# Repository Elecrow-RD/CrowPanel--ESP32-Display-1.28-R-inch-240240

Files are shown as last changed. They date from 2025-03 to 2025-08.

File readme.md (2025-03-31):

### 1, Product picture

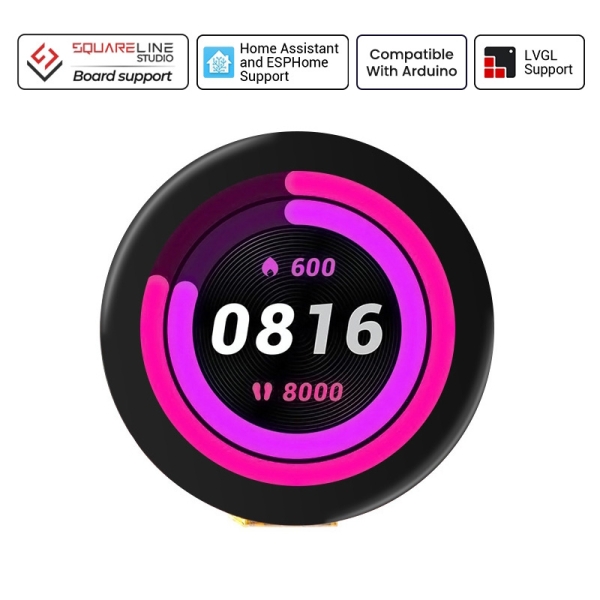
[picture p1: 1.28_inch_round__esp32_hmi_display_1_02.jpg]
1.28_inch_round__esp32_hmi_display_1_02


### 2, Product version number

| | Hardware | Software | Remark |
| ---- | --- | --- | --- |
| 1 | V1.0 | V1.0 | latest |

### 3, product information

#### Display Module Specifications

| Main Chip | ESP32-C3 |
| --- | --- |
| Processor | 32-bit RISC-V single-core processor, up to 160 MHz |
| Memory | 384 KB ROM400 KB SRAM (16 KB for cache)8 KB SRAM in RTC |
| Size | 1.28 inch |
| Resolution | 240*240 |
| Signal Interface | SPI |
| Touch Type | Capacitive Touch |
| Panel Type | TFT LCD, IPS Panel |
| Color Depth | 262K |
| Brightness | 350 cd/m² |
| Viewing Angle | 178° |
| Button | Rest Butto, Boot Button, Custom Button |
| Interface | Type-C Interface, Battery Interface |
| Encoder | With Button Function, Without Pin (Pin Size: 0.8mm*0.8mm) |
| Operation Power  | Module: DC5VMain Chip: 3.3V |
| Active Area | 32.51*32.51mm |
| Dimensions | 42*42*9.8mm |
| Net Weight | 15g |

### 4, Use the driver module

### 5,Quick Start

##### Arduino IDE starts

1.Download the library files used by this product to the 'libraries' folder.

C:\Users\Documents\Arduino\libraries\



2.Open the Arduino IDE

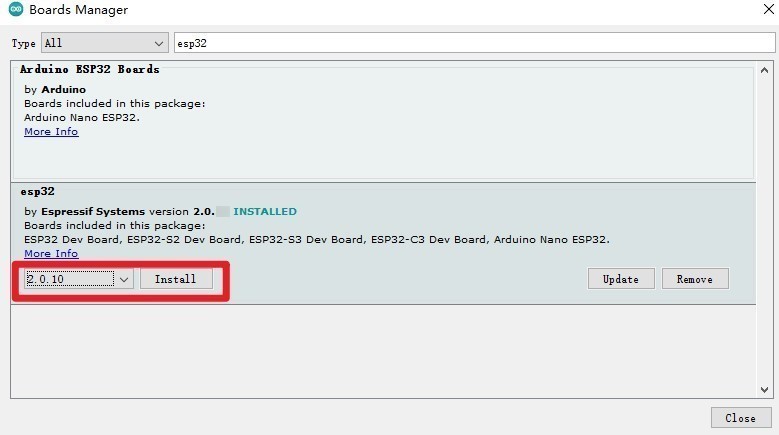
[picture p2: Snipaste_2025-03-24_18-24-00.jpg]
Snipaste_2025-03-24_18-24-00


3.Open the code configuration environment and burn it

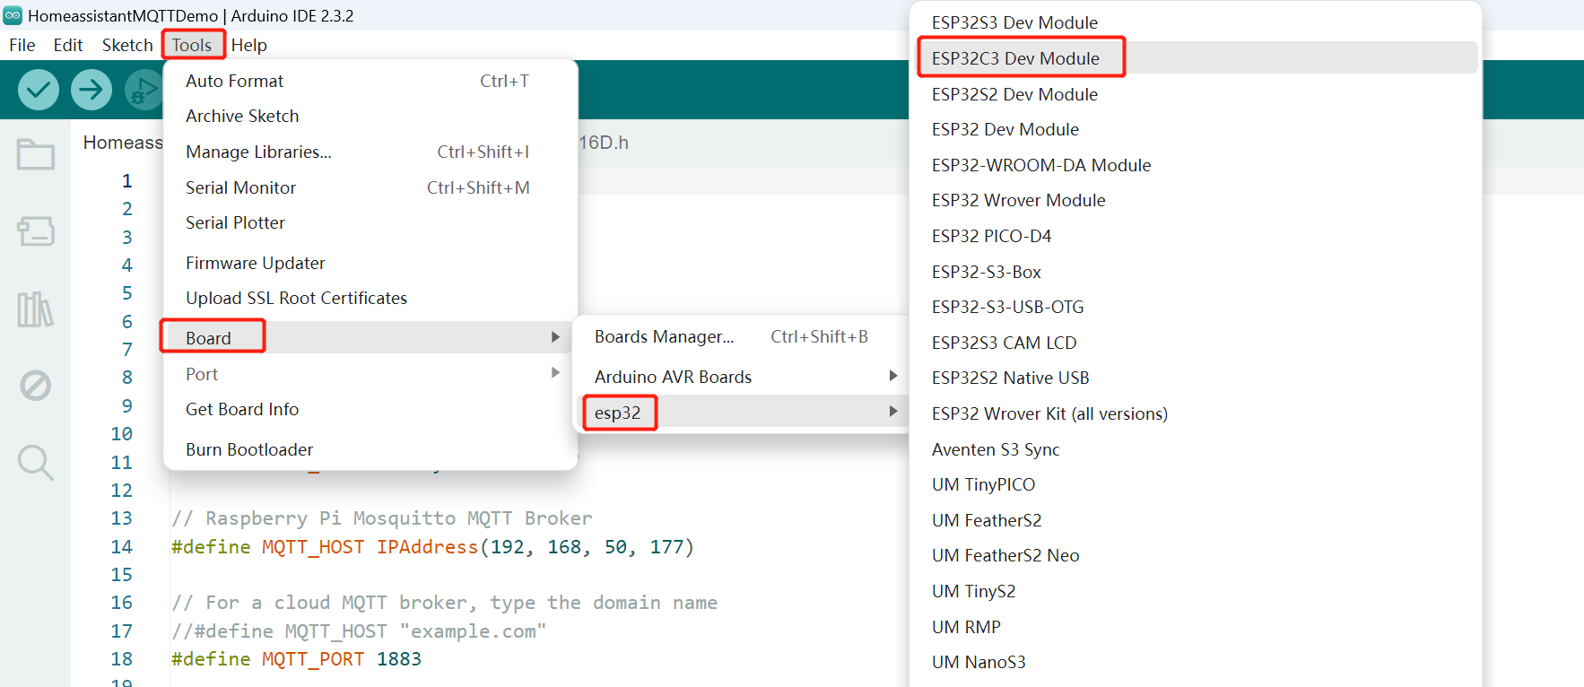
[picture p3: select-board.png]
select-board


##### Micropython starts

1,Right-click on an empty space in the project folder and select "Thonny" to open the project.

thonny

2,In thonny software, select the master and port, then run the program

thonny2

### 6,Folder structure.

|--3D file： Contains 3D model files (.stp) for the hardware. These files can be used for visualization, enclosure design, or integration into CAD software.

|--Datasheet: Includes datasheets for components used in the project, providing detailed specifications, electrical characteristics, and pin configurations.

|--Eagle_SCH&PCB: Contains **Eagle CAD** schematic (`.sch`) and PCB layout (`.brd`) files. These are used for circuit design and PCB manufacturing.

|--example: Provides example code and projects to demonstrate how to use the hardware and libraries. These examples help users get started quickly.

|--factory_firmware: Stores pre-compiled factory firmware that can be directly flashed onto the device. This ensures the device runs the default functionality.

|--factory_sourcecode: Contains the source code for the factory firmware, allowing users to modify and rebuild the firmware as needed.

### 7,Pin definition

#define I2C_SDA 4

#define I2C_SCL 5

#define TP_INT 0

#define TP_RST -1

//encoder

#define ENCODER_A_PIN 19

#define ENCODER_B_PIN 18

#define SWITCH_PIN    8

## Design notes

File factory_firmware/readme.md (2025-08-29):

# How to install the factory demo firmware with flash download tool?

#### 1.Preparation:

- USB C cable
- Laptop/PC
- Crowpanel Advance HMI ESP32 AI Display
- Flash download tool

Check whether the materials on the PCBA board are defective. Such as less material, false welding, tin and other bad phenomena.

#### 2.Flash the firmware 

##### Step1 Connect the ESP32 display to the laptop/PC with USB-C cable. The power indicator will light up.

flash-0

##### Step2 Open the flash download tool. 

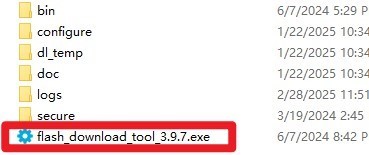
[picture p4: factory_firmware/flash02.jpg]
flash02


For the  Crowpanel Advance HMI ESP32 AI Display, the chip select ESP32-C3:

![Uploading flash03.jpg…]()

##### Step3

①Choose the firmware files;

flash0

②Enter the address: 

boot_app0.bin------0xe000

xxxx.ino.bin--------0x10000

xxxx.ino.bootloader.bin------0x0

xxxx.ino.partitions.bin-------0x8000

③Check the firmware files;

④Select the correct port number;

⑤Click “Start” to download

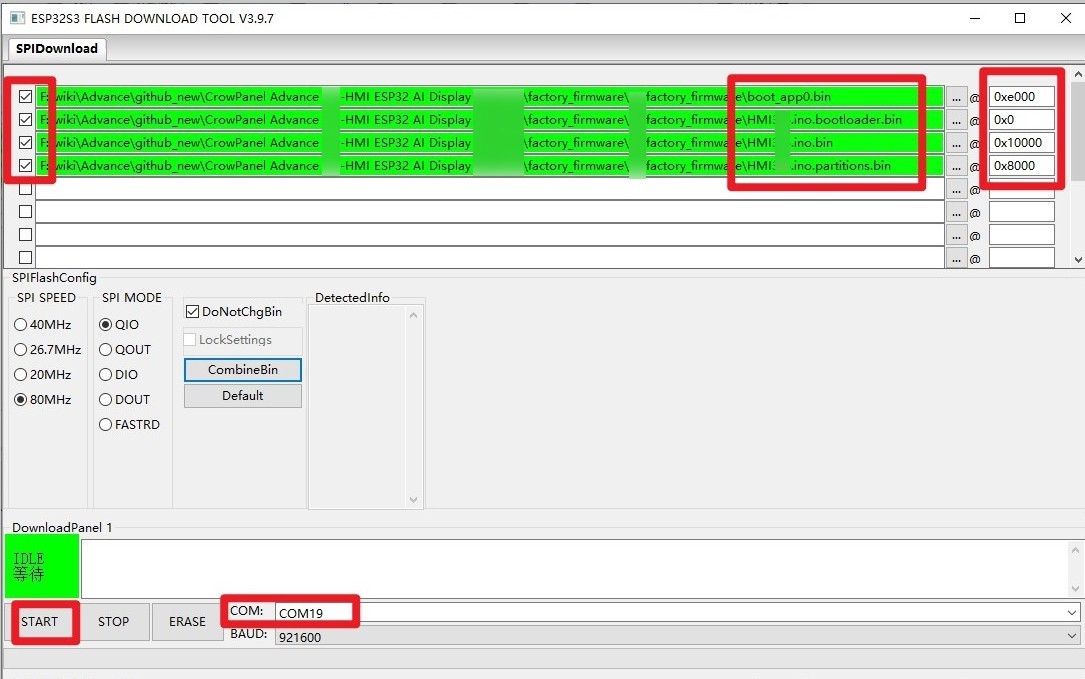
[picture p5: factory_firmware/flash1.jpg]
flash1


##### Step5 After the download is complete, blue FINISH will be displayed, and the progress bar at the bottom shows that it has come to an end.

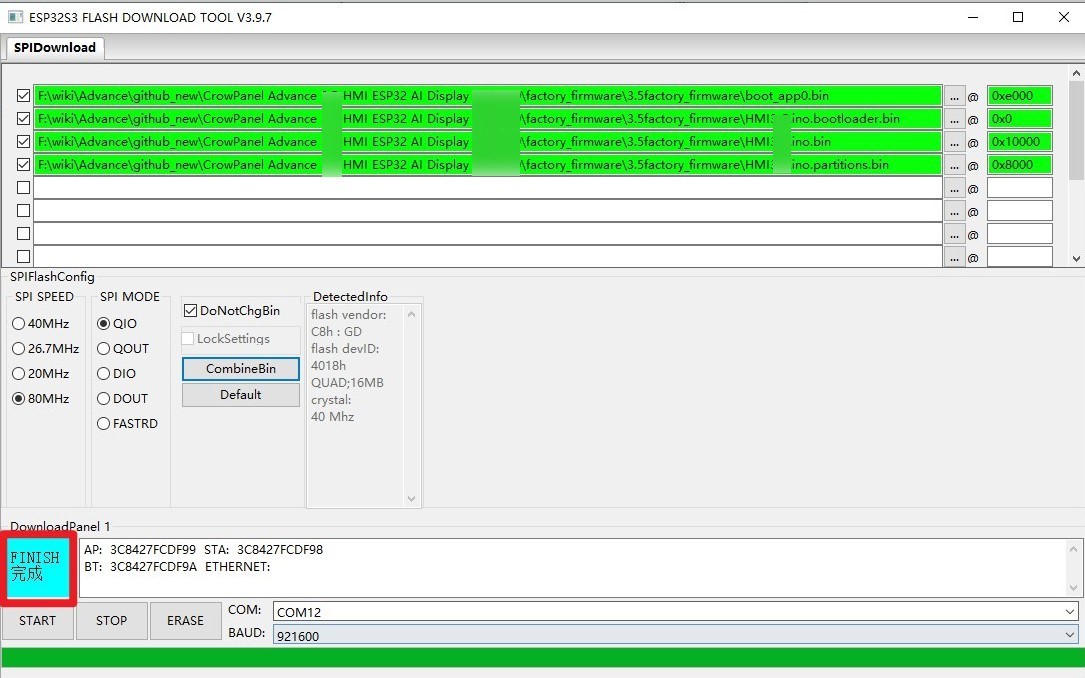
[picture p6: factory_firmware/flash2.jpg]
flash2


##### Step6 Press the reset button to show the demo.

flash8

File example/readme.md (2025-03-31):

**Arduino**: This folder contains sample programs for the Arduino platform, which is known for its ease of use and versatility in creating interactive electronic projects.

#### NOTE!!!:When running this program , you need to download the officially provided libraries and place them in the libraries of arduino. esp32 version needs to be 2.0.10 the version of the libraries is the same as the officially provided version.

Link to the corresponding course wiki:https://www.elecrow.com/wiki/ESP32_1.28-inch_Round_Display_Tutorial.html#tutorial-on-arduino-ide

### homeassistant：

https://www.elecrow.com/wiki/ESP32_1.28-inch_Round_Display_Tutorial.html

### micropython ：

https://www.elecrow.com/wiki/ESP32_1.28-inch_Round_Display_Tutorial.html#tutorial-on-thonny-ide

### Chronos APP:

https://www.elecrow.com/wiki/ESP32_1.28-inch_Round_Display_Chronos_Tutorial.html

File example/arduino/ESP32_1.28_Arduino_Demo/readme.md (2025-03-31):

### Libraries Introduction

1. **async-mqtt-client-develop**
   - An asynchronous MQTT client library for communication with MQTT servers.

2. **ESPAyncUDP**
   - An asynchronous UDP library designed for ESP8266 and ESP32 microcontrollers, compatible with Arduino environment.

3. **LovyanGFX**
   - A graphics library that supports various display devices, commonly used to drive TFT displays and other graphical interfaces.

4. **Lvgi**
   - Likely a specific-purpose graphics or interface library.

5. **lv_conf.h**
   - Configuration file for LVGL (Light and Versatile Graphics Library), used to set and customize the behavior and features of LVGL.

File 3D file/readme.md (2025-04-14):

#### Download link address：
https://www.elecrow.com/download/product/DIS12824D/CrowPanel_ESP32_Display1.28_3D_file.zip

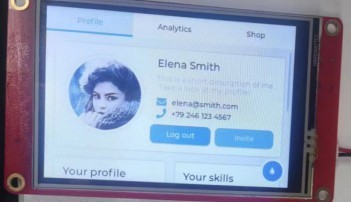
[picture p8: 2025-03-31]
factory_firmware/flash8.jpg

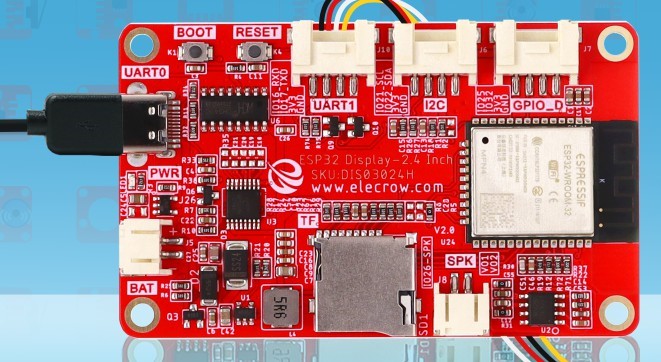
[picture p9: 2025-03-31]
factory_firmware/flash01.jpg

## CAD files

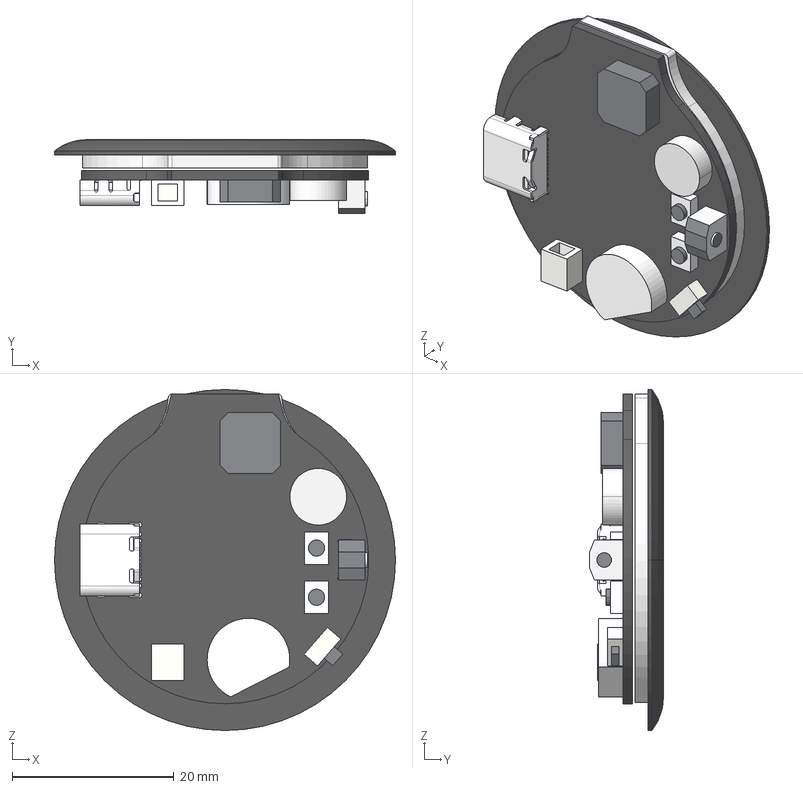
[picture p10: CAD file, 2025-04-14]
3D file/CrowPanel ESP32 Display1.28_asm(2).stp
42.1 x 9.10 x 42.1 mm
LCD-MIANBAN
LCD-JIAOTIE
PCB
TYPE_C_20241129

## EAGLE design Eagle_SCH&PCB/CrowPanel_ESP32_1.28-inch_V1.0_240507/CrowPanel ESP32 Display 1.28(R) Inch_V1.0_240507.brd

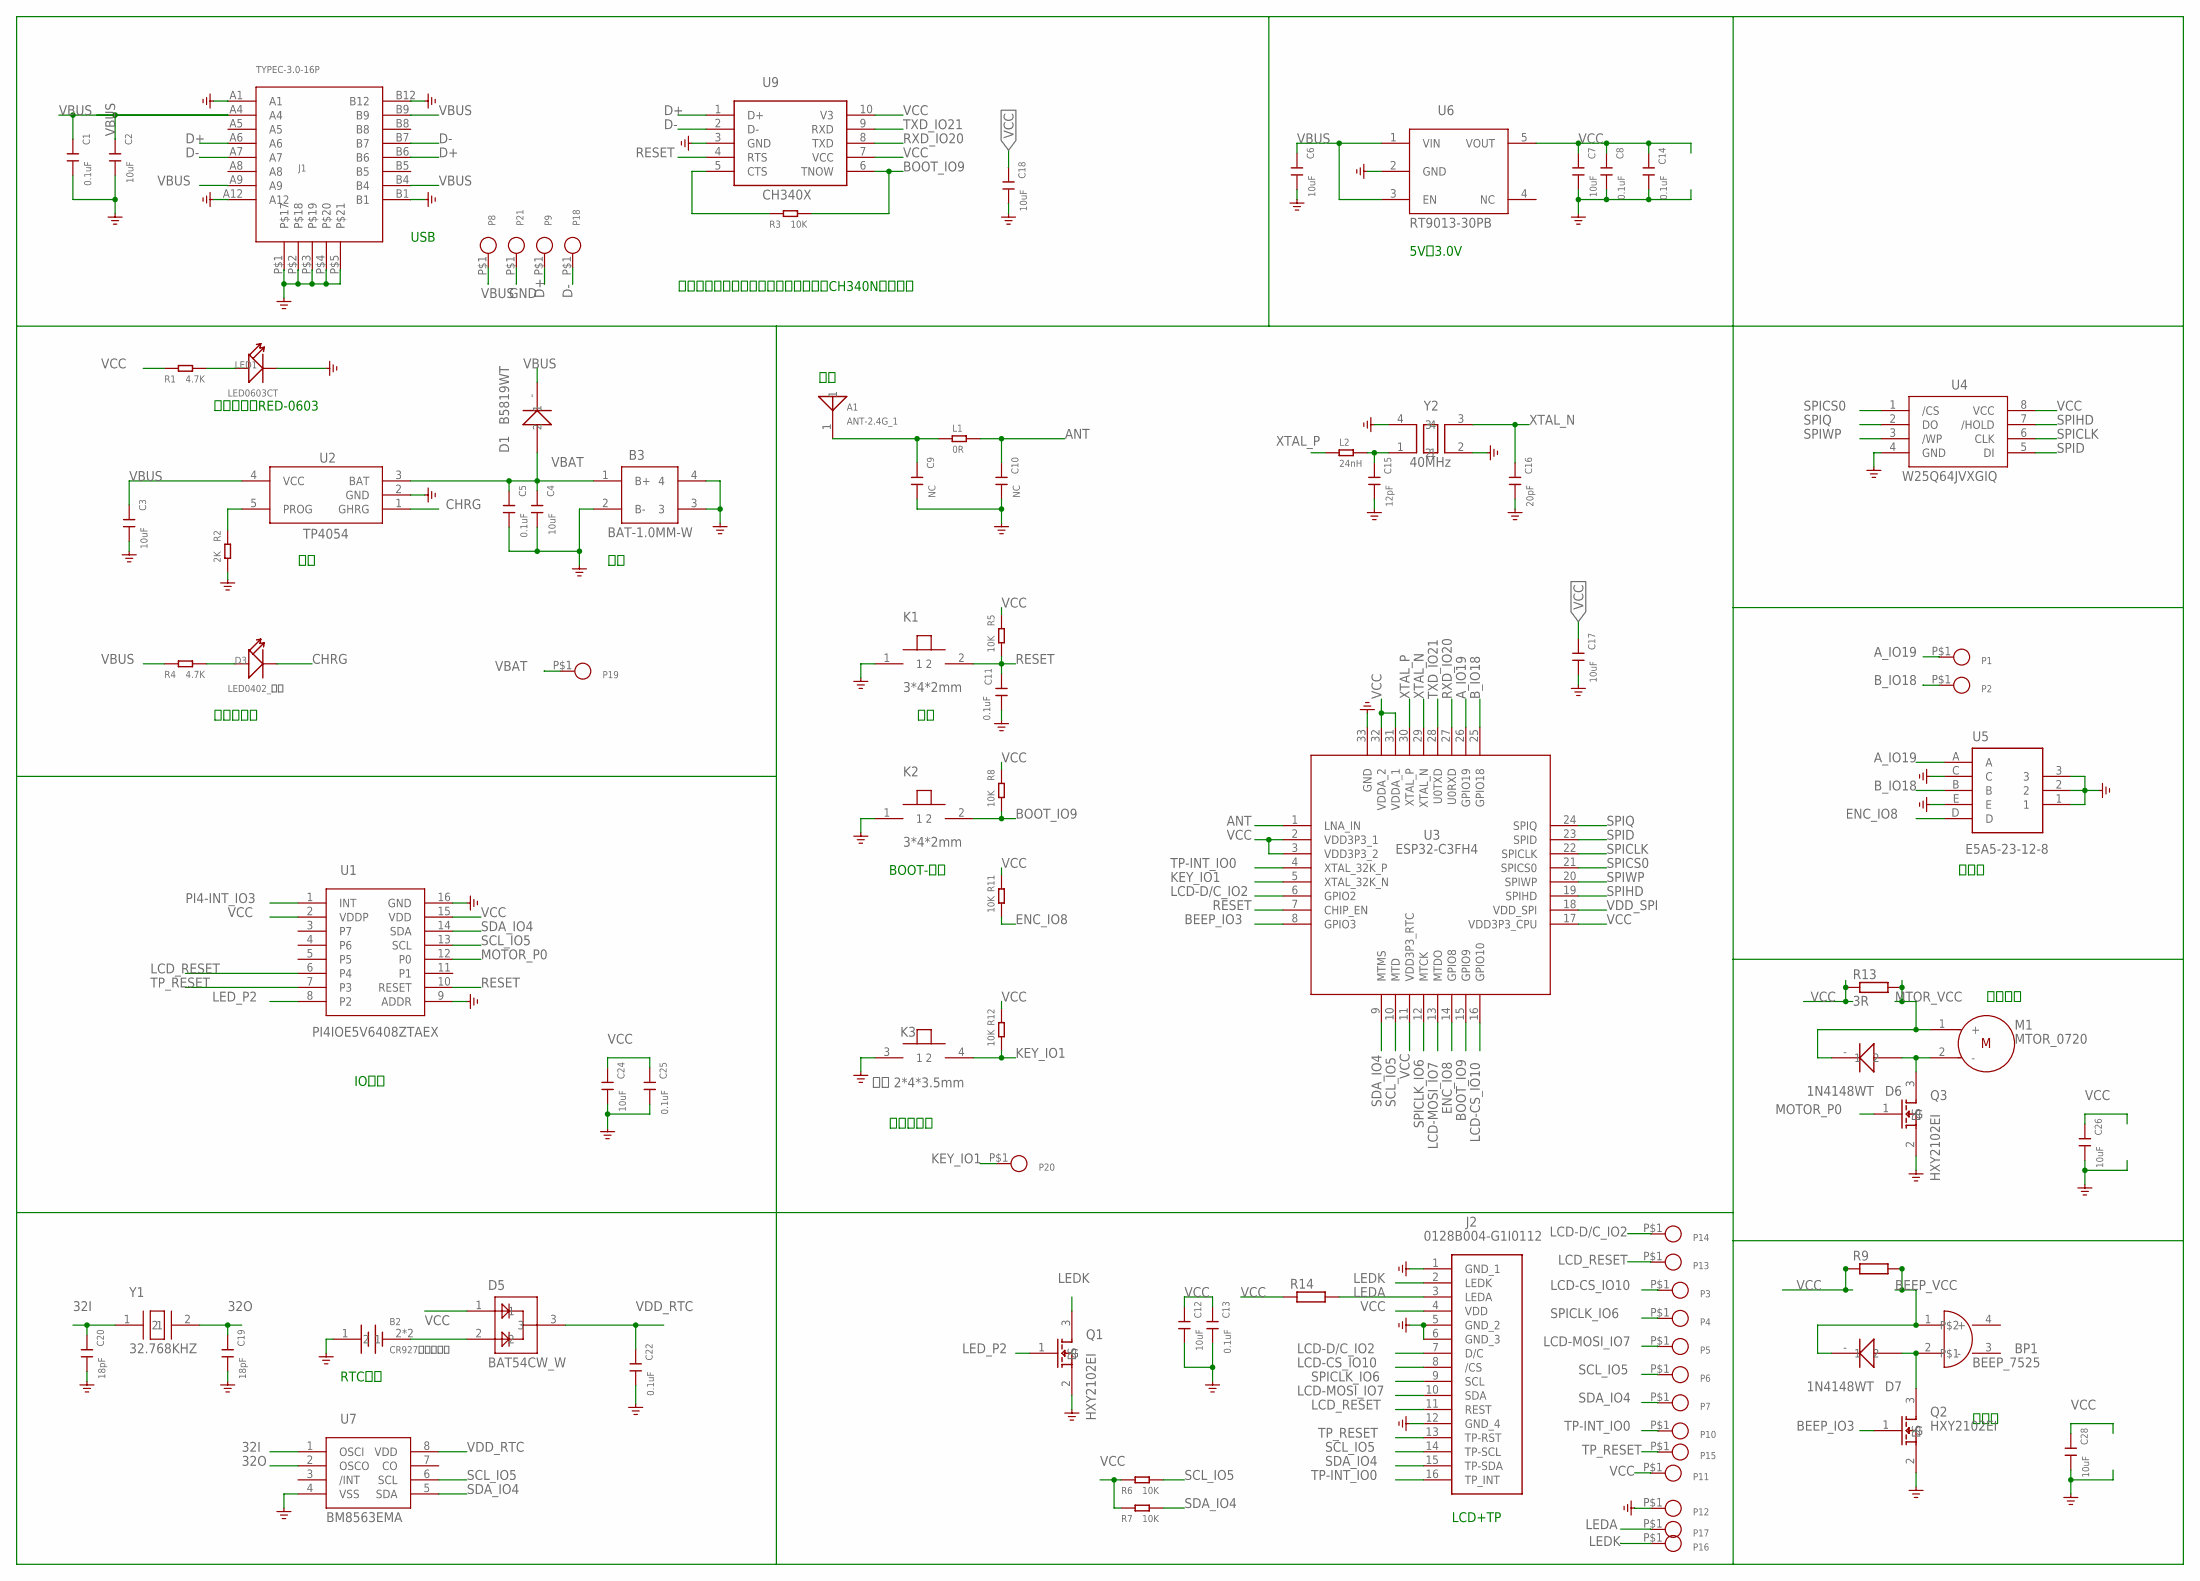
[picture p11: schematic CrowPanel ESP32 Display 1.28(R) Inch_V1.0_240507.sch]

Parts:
A1: ANT-2.4G_1
B2: CR927纽扣电池座; POWER-BAT
B3: BAT-1.0MM-W; SH1.0MM-W
BP1: BEEP_7525
C1, C5, C8, C11, C13, C14, C22, C25: 0.1uF; 0201_W
C2, C3, C4, C6, C7, C12, C17, C18, C24, C26, C28: 10uF; 0402
C9, C10: NC; 0201_W
C15: 12pF; 0201_W
C16: 20pF; 0201_W
C19, C20: 18pF; 0201_W
D1: B5819WT; SOD-523
D3: LED0402_红色; LED-0402_W
D5: BAT54CW_W; SOT-323_W
D6, D7: 1N4148WT; SOD-523
J1: TYPEC-3.0-16P; KEVIN_3.0TYPEC-SMD
J2: 0128B004-G1I0112; 16PIN-SMD
K1, K2: 3*4*2mm; KEY-3X4_W
K3: 侧贴 2*4*3.5mm; KEY-3.5X4.5_C
L1: 0R; 0201_W
L2: 24nH; 0201_W
LED1: LED0603CT; LED-0603-CE
M1: MTOR_0720; MOTOR-1
P1, P2, P3, P4, P5, P6, P7, P8, P9, P10, P11, P12, P13, P14, P15, P16, P17, P18, P19, P20, P21: PADPAD-1.0MM; PAD-1.0MM
Q1, Q2, Q3: HXY2102EI; SOT-323_W
R1, R4: 4.7K; 0201_W
R2: 2K; 0201_W
R3, R5, R6, R7, R8, R11, R12: 10K; 0201_W
R9, R14: R-EU_R0402; R0402
R13: 3R; R0402
U1: PI4IOE5V6408ZTAEX; UQFN-16
U2: TP4054; SOP23-5
U3: ESP32-C3FH4; QFN-32_W
U4: W25Q64JVXGIQ; XSON4X4
U5: E5A5-23-12-8
U6: RT9013-30PB; SOT23-5_W
U7: BM8563EMA; MSOP-8_W
U9: CH340X; MSOP-10_W
Y1: 32.768KHZ; 3215_W
Y2: 40MHz; 3225_W

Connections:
32I: C20.1, U7.1 (OSCI), Y1.1
32O: C19.1, U7.2 (OSCO), Y1.2
ANT: C10.1, L1.2, U3.1 (LNA_IN)
A_IO19: P1.P$1, U3.26 (GPIO19), U5.A
BEEP_IO3: Q2.1 (G), U3.8 (GPIO3)
BEEP_VCC: BP1.1 (+), D7.- (2), R9.2
BOOT_IO9: K2.2, R3.2, R8.2, U3.15 (GPIO9), U9.6 (TNOW)
B_IO18: P2.P$1, U3.25 (GPIO18), U5.B
CHRG: D3.2 (-), U2.1 (GHRG)
D+: J1.A6, J1.B6, P9.P$1, U9.1 (D+)
D-: J1.A7, J1.B7, P18.P$1, U9.2 (D-)
ENC_IO8: R11.2, U3.14 (GPIO8), U5.D
GND: B2.1, B3.2 (B-), B3.3, B3.4, C1.2, C2.2, C3.2, C4.2, C5.2, C6.2, C7.2, C8.2, C9.2, C10.2, C11.2, C12.2, C13.2, C14.2, C15.2, C16.2, C17.2, C18.2, C19.2, C20.2, C22.2, C24.2, C25.2, C26.2, C28.2, J1.A1, J1.A12, J1.B1, J1.B12, J1.P$1, J1.P$2, J1.P$3, J1.P$4, J1.P$5, J2.1 (GND_1), J2.5 (GND_2), J2.6 (GND_3), J2.12 (GND_4), K1.1, K2.1, K3.3 (1), LED1.2 (-), P12.P$1, P21.P$1, Q1.2 (S), Q2.2 (S), Q3.2 (S), R2.2, U1.9 (ADDR), U1.16 (GND), U2.2 (GND), U3.33 (GND), U4.4 (GND), U5.1, U5.2, U5.3, U5.C, U5.E, U6.2 (GND), U7.4 (VSS), U9.3 (GND), Y2.2, Y2.4
KEY_IO1: K3.4 (2), P20.P$1, R12.2, U3.5 (XTAL_32K_N)
LCD-CS_IO10: J2.8 (/CS), P3.P$1, U3.16 (GPIO10)
LCD-D/C_IO2: J2.7 (D/C), P14.P$1, U3.6 (GPIO2)
LCD-MOSI_IO7: J2.10 (SDA), P5.P$1, U3.13 (MTDO)
LCD_RESET: J2.11 (REST), P13.P$1, U1.6 (P4)
LEDA: J2.3 (LEDA), P17.P$1, R14.2
LEDK: J2.2 (LEDK), P16.P$1, Q1.3 (D)
LED_P2: Q1.1 (G), U1.8 (P2)
MOTOR_P0: Q3.1 (G), U1.12 (P0)
MTOR_VCC: D6.- (2), M1.1 (+), R13.2
unnamed: LED1.1 (+), R1.2
unnamed: R2.1, U2.5 (PROG)
unnamed: C15.1, L2.2, Y2.1
unnamed: R3.1, U9.5 (CTS)
unnamed: D3.1 (+), R4.2
unnamed: BP1.2 (-), D7.+ (1), Q2.3 (D)
unnamed: D6.+ (1), M1.2 (-), Q3.3 (D)
unnamed: A1.1, C9.1, L1.1
unnamed: B2.2, B2.3 (2), D5.2
PI4-INT_IO3: U1.1 (INT)
RESET: C11.1, K1.2, R5.2, U1.10 (RESET), U3.7 (CHIP_EN), U9.4 (RTS)
RXD_IO20: U3.27 (U0RXD), U9.8 (TXD)
SCL_IO5: J2.14 (TP-SCL), P6.P$1, R6.2, U1.13 (SCL), U3.10 (MTD), U7.6 (SCL)
SDA_IO4: J2.15 (TP-SDA), P7.P$1, R7.2, U1.14 (SDA), U3.9 (MTMS), U7.5 (SDA)
SPICLK: U3.22 (SPICLK), U4.6 (CLK)
SPICLK_IO6: J2.9 (SCL), P4.P$1, U3.12 (MTCK)
SPICS0: U3.21 (SPICS0), U4.1 (/CS)
SPID: U3.23 (SPID), U4.5 (DI)
SPIHD: U3.19 (SPIHD), U4.7 (/HOLD)
SPIQ: U3.24 (SPIQ), U4.2 (DO)
SPIWP: U3.20 (SPIWP), U4.3 (/WP)
TP-INT_IO0: J2.16 (TP_INT), P10.P$1, U3.4 (XTAL_32K_P)
TP_RESET: J2.13 (TP-RST), P15.P$1, U1.7 (P3)
TXD_IO21: U3.28 (U0TXD), U9.9 (RXD)
VBAT: B3.1 (B+), C4.1, C5.1, D1.+ (1), P19.P$1, U2.3 (BAT)
VBUS: C1.1, C2.1, C3.1, C6.1, D1.- (2), J1.A4, J1.A9, J1.B4, J1.B9, P8.P$1, R4.1, U2.4 (VCC), U6.1 (VIN), U6.3 (EN)
VCC: C7.1, C8.1, C12.1, C13.1, C14.1, C17.1, C18.1, C24.1, C25.1, C26.1, C28.1, D5.1, J2.4 (VDD), P11.P$1, R1.1, R5.1, R6.1, R7.1, R8.1, R9.1, R11.1, R12.1, R13.1, R14.1, U1.2 (VDDP), U1.15 (VDD), U3.2 (VDD3P3_1), U3.3 (VDD3P3_2), U3.11 (VDD3P3_RTC), U3.17 (VDD3P3_CPU), U3.31 (VDDA_1), U3.32 (VDDA_2), U4.8 (VCC), U6.5 (VOUT), U9.7 (VCC), U9.10 (V3)
VDD_RTC: C22.1, D5.3, U7.8 (VDD)
VDD_SPI: U3.18 (VDD_SPI)
XTAL_N: C16.1, U3.29 (XTAL_N), Y2.3
XTAL_P: L2.1, U3.30 (XTAL_P)

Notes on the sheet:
电源指示灯RED-0603
USB
5V转3.0V
LCD+TP
BOOT-升级
蜂鸣器
振动马达
编码器
IO扩展
自定义按键
RTC电池
充电指示灯
因部分电脑不能进入上位机，考虑更换CH340N方案验证

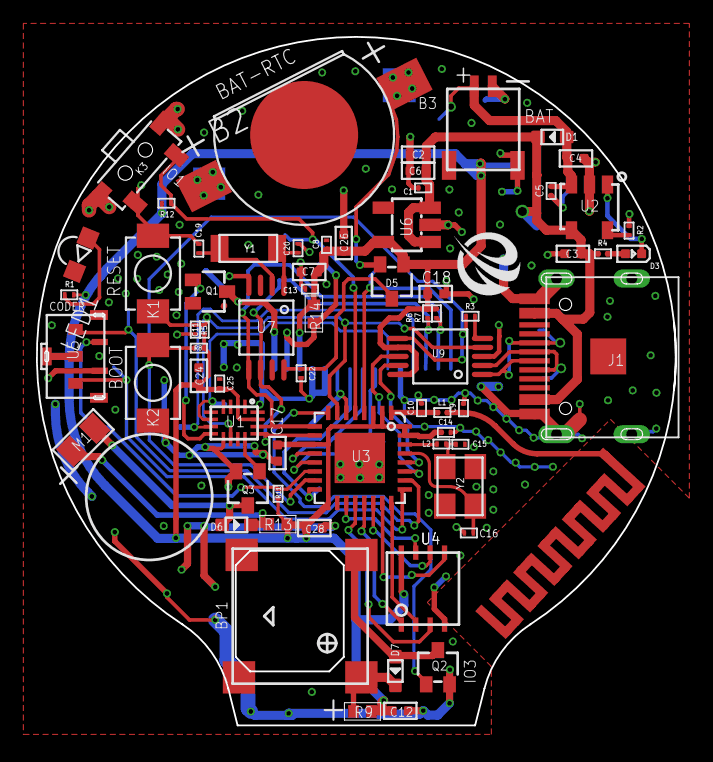
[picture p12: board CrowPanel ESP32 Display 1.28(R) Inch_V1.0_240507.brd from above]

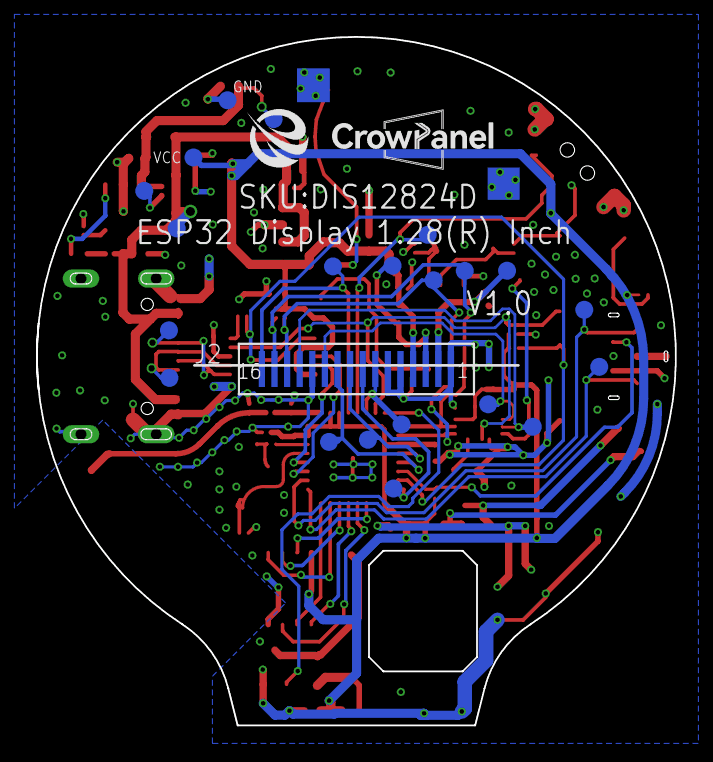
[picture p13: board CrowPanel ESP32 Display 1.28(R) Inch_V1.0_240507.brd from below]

Board: 2 copper layers, 35.5 x 38.2 mm, 90 parts (22 on the bottom side), 52 nets.

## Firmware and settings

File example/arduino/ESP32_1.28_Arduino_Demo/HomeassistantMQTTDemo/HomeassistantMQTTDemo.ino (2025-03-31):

#define LGFX_USE_V1
#include "Arduino.h"
#include <lvgl.h>
#include "demos/lv_demos.h"
#include <LovyanGFX.hpp>
#include "CST816D.h"
#include <WiFi.h>
#include <AsyncMqttClient.h>

#define WIFI_SSID "yanfa_software"
#define WIFI_PASSWORD "yanfa-123456"

// Raspberry Pi Mosquitto MQTT Broker
#define MQTT_HOST IPAddress(192, 168, 50, 177)

// For a cloud MQTT broker, type the domain name
//#define MQTT_HOST "example.com"
#define MQTT_PORT 1883

// Temperature MQTT Topics
#define MQTT_PUB_Vibration_Motor_S  "esp32/VibrationMotor/state"
#define MQTT_PUB_Vibration_Motor_C "esp32/VibrationMotor/command"
#define mqtt_username  "sea"
#define mqtt_password  "lisihai525"

AsyncMqttClient mqttClient;
TimerHandle_t mqttReconnectTimer;
TimerHandle_t wifiReconnectTimer;

// I2C pins
#define I2C_SDA 4
#define I2C_SCL 5
// Touch panel interrupt and reset pins
#define TP_INT 0
#define TP_RST -1

// I2C address for the I/O extender
#define PI4IO_I2C_ADDR 0x43

// Buffer size definition
#define buf_size 120

char Vibration_Motor_flag = 0;
char Vibration_Motor_flag_Lock = 0;
//char Change_Color_flag_Lock = 0;
// LGFX class definition for display device interface
class LGFX : public lgfx::LGFX_Device
{
    // Internal components of the LGFX class
    lgfx::Panel_GC9A01 _panel_instance;
    lgfx::Bus_SPI _bus_instance;
  public:
    LGFX(void)
    {
      {
        // Configuration for the SPI bus and panel
        auto cfg = _bus_instance.config();
        cfg.spi_host = SPI2_HOST;
        cfg.spi_mode = 0;
        cfg.freq_write = 80000000;
        cfg.freq_read = 20000000;
        cfg.spi_3wire = true;
        cfg.use_lock = true;
        cfg.dma_channel = SPI_DMA_CH_AUTO;
        cfg.pin_sclk = 6;
        cfg.pin_mosi = 7;
        cfg.pin_miso = -1;
        cfg.pin_dc = 2;
        _bus_instance.config(cfg);
        _panel_instance.setBus(&_bus_instance);
      }
      {
        auto cfg = _panel_instance.config();
        cfg.pin_cs = 10;
        cfg.pin_rst = -1;
        cfg.pin_busy = -1;
        cfg.memory_width = 240;
        cfg.memory_height = 240;
        cfg.panel_width = 240;
        cfg.panel_height = 240;
        cfg.offset_x = 0;
        cfg.offset_y = 0;
        cfg.offset_rotation = 0;
        cfg.dummy_read_pixel = 8;
        cfg.dummy_read_bits = 1;
        cfg.readable = false;
        cfg.invert = true;
        cfg.rgb_order = false;
        cfg.dlen_16bit = false;
        cfg.bus_shared = false;
        _panel_instance.config(cfg);
      }
      setPanel(&_panel_instance);
    }
};

// Global instances for the display and touch screen
LGFX tft;
CST816D touch(I2C_SDA, I2C_SCL, TP_RST, TP_INT);

/*Change to your screen resolution*/
static const uint32_t screenWidth = 240;
static const uint32_t screenHeight = 240;

static lv_disp_draw_buf_t draw_buf;
static lv_color_t buf[2][screenWidth * buf_size];

#if LV_USE_LOG != 0
// Custom print function for LVGL debugging
void my_print(lv_log_level_t level, const char *file, uint32_t line, const char *fn_name, const char *dsc)
{
  Serial.printf("%s(%s)@%d->%s\r\n", file, fn_name, line, dsc);
  Serial.flush();
}
#endif

// Function to handle flushing of display buffer to the screen
void my_disp_flush(lv_disp_drv_t *disp, const lv_area_t *area, lv_color_t *color_p)
{
  if (tft.getStartCount() == 0)
  {
    tft.endWrite();
  }

  tft.pushImageDMA(area->x1, area->y1, area->x2 - area->x1 + 1, area->y2 - area->y1 + 1, (lgfx::swap565_t *)&color_p->full);

  lv_disp_flush_ready(disp); /* tell lvgl that flushing is done */
}

// Function to read touchpad input
void my_touchpad_read(lv_indev_drv_t *indev_driver, lv_indev_data_t *data)
{
  bool touched;
  uint8_t gesture;
  uint16_t touchX, touchY;
  touched = touch.getTouch(&touchX, &touchY, &gesture);
  if (!touched)
  {
    data->state = LV_INDEV_STATE_REL;
  }
  else
  {
    data->state = LV_INDEV_STATE_PR;
    /*Set the coordinates*/
    data->point.x = touchX;
    data->point.y = touchY;
  }
}

// Function to initialize I/O extender
void init_IO_extender() {
  Wire.beginTransmission(PI4IO_I2C_ADDR);
  Wire.write(0x01); // test register
  Wire.endTransmission();
  Wire.requestFrom(PI4IO_I2C_ADDR, 1);
  uint8_t rxdata = Wire.read();
  Serial.print("Device ID: ");
  Serial.println(rxdata, HEX);

  Wire.beginTransmission(PI4IO_I2C_ADDR);
  Wire.write(0x03); // IO direction register
  Wire.write((1 << 0) | (1 << 1) | (1 << 2) | (1 << 3) | (1 << 4)); // set pins 0, 1, 2 as outputs
  Wire.endTransmission();

  Wire.beginTransmission(PI4IO_I2C_ADDR);
  Wire.write(0x07); // Output Hi-Z register
  Wire.write(~((1 << 0) | (1 << 1) | (1 << 2) | (1 << 3) | (1 << 4))); // set pins 0, 1, 2 low
  Wire.endTransmission();
}

// Function to set I/O pin state on the extender
void set_pin_io(uint8_t pin_number, bool value) {

  Wire.beginTransmission(PI4IO_I2C_ADDR);
  Wire.write(0x05); // test register
  Wire.endTransmission();
  Wire.requestFrom(PI4IO_I2C_ADDR, 1);
  uint8_t rxdata = Wire.read();
  //  Serial.print("Before the change: ");
  //  Serial.println(rxdata, HEX);

  Wire.beginTransmission(PI4IO_I2C_ADDR);
  Wire.write(0x05); // Output register

  if (!value)
    Wire.write((~(1 << pin_number)) & rxdata); // set pin low
  else
    Wire.write((1 << pin_number) | rxdata); // set pin high
  Wire.endTransmission();

  Wire.beginTransmission(PI4IO_I2C_ADDR);
  Wire.write(0x05); // test register
  Wire.endTransmission();
  Wire.requestFrom(PI4IO_I2C_ADDR, 1);
  rxdata = Wire.read();
  //  Serial.print("after the change: ");
  //  Serial.println(rxdata, HEX);
}


void connectToWifi() {
  Serial.println("Connecting to Wi-Fi...");
  WiFi.begin(WIFI_SSID, WIFI_PASSWORD);
}

void connectToMqtt() {
  Serial.println("Connecting to MQTT...");
  mqttClient.connect();
}

void WiFiEvent(WiFiEvent_t event) {
  Serial.printf("[WiFi-event] event: %d\n", event);
  switch (event) {
    case SYSTEM_EVENT_STA_GOT_IP:
      Serial.println("WiFi connected");
      Serial.println("IP address: ");
      Serial.println(WiFi.localIP());
      connectToMqtt();
      break;
    case SYSTEM_EVENT_STA_DISCONNECTED:
      Serial.println("WiFi lost connection");
      xTimerStop(mqttReconnectTimer, 0); // ensure we don't reconnect to MQTT while reconnecting to Wi-Fi
      xTimerStart(wifiReconnectTimer, 0);
      break;
  }
}

void onMqttConnect(bool sessionPresent) {
  Serial.println("Connected to MQTT.");
  Serial.print("Session present: ");
  Serial.println(sessionPresent);
  uint16_t packetIdSub = mqttClient.subscribe(MQTT_PUB_Vibration_Motor_C, 2);
  Serial.print("Subscribing at QoS 2, packetId: ");
  Serial.println(packetIdSub);
}

void onMqttDisconnect(AsyncMqttClientDisconnectReason reason) {
  Serial.println("Disconnected from MQTT.");
  if (WiFi.isConnected()) {
    xTimerStart(mqttReconnectTimer, 0);
  }
}

void onMqttSubscribe(uint16_t packetId, uint8_t qos) {
  Serial.println("Subscribe acknowledged.");
  Serial.print("  packetId: ");
  Serial.println(packetId);
  Serial.print("  qos: ");
  Serial.println(qos);
}

void onMqttUnsubscribe(uint16_t packetId) {
  Serial.println("Unsubscribe acknowledged.");
  Serial.print("  packetId: ");
  Serial.println(packetId);
}

lv_obj_t * sw1;

void onMqttMessage(char* topic, char* payload, AsyncMqttClientMessageProperties properties, size_t len, size_t index, size_t total)
{
  Serial.println("Publish received.");
  for (int i = 0; i < len; i++) {
    Serial.print((char) payload[i]);
  }
  Serial.println("");
  if (strncmp(payload, "ON", 2) == 0) {
    Vibration_Motor_flag_Lock = 1;
    Vibration_Motor_flag = 1;
    mqttClient.publish(MQTT_PUB_Vibration_Motor_S, 0, true, "ON");
    lv_obj_add_state(sw1, LV_STATE_CHECKED);
  }
  if (strncmp(payload, "OFF", 3) == 0) {
    Vibration_Motor_flag_Lock = 1;
    Vibration_Motor_flag = 0;
    mqttClient.publish(MQTT_PUB_Vibration_Motor_S, 0, true, "OFF");
    lv_obj_clear_state(sw1, LV_STATE_CHECKED);
  }
}

void onMqttPublish(uint16_t packetId) {
  Serial.print("Publish acknowledged.");
  Serial.print("  packetId: ");
  Serial.println(packetId);
}

void setup()
{
  // Initialization of serial communication, I2C, display, touch screen, and LVGL
  Serial.begin(115200); /* prepare for possible serial debug */
  Serial.println("I am LVGL_Arduino");
  Wire.begin(4, 5);
  init_IO_extender();
  delay(100);
  set_pin_io(3, true);
  set_pin_io(4, true);
  set_pin_io(2, true);

  mqttReconnectTimer = xTimerCreate("mqttTimer", pdMS_TO_TICKS(2000), pdFALSE, (void*)0, reinterpret_cast<TimerCallbackFunction_t>(connectToMqtt));
  wifiReconnectTimer = xTimerCreate("wifiTimer", pdMS_TO_TICKS(2000), pdFALSE, (void*)0, reinterpret_cast<TimerCallbackFunction_t>(connectToWifi));
  WiFi.onEvent(WiFiEvent);
  mqttClient.onConnect(onMqttConnect);
  mqttClient.onDisconnect(onMqttDisconnect);
  mqttClient.onSubscribe(onMqttSubscribe);
  mqttClient.onUnsubscribe(onMqttUnsubscribe);
  mqttClient.onMessage(onMqttMessage);
  mqttClient.onPublish(onMqttPublish);
  mqttClient.setServer(MQTT_HOST, MQTT_PORT);
  // If your broker requires authentication (username and password), set them below
  mqttClient.setCredentials(mqtt_username, mqtt_password);

  connectToWifi();

  tft.init();
  tft.initDMA();
  tft.startWrite();
  tft.setColor(0, 0, 0);

  tft.fillScreen(TFT_BLACK);
  delay(200);
  touch.begin();
  lv_init();
#if LV_USE_LOG != 0
  //lv_log_register_print_cb(my_print); /* register print function for debugging */
#endif

  lv_disp_draw_buf_init(&draw_buf, buf[0], buf[1], screenWidth * buf_size);

  /*Initialize the display*/
  static lv_disp_drv_t disp_drv;
  lv_disp_drv_init(&disp_drv);
  /*Change the following line to your display resolution*/
  disp_drv.hor_res = screenWidth;
  disp_drv.ver_res = screenHeight;
  disp_drv.flush_cb = my_disp_flush;
  disp_drv.draw_buf = &draw_buf;
  lv_disp_drv_register(&disp_drv);

  /*Initialize the (dummy) input device driver*/
  static lv_indev_drv_t indev_drv;
  lv_indev_drv_init(&indev_drv);
  indev_drv.type = LV_INDEV_TYPE_POINTER;
  indev_drv.read_cb = my_touchpad_read;
  lv_indev_drv_register(&indev_drv);


#if 0
  /* Create simple label */
  lv_obj_t *label = lv_label_create( lv_scr_act() );
  lv_label_set_text( label, "Hello Arduino! (V8.0.X)" );
  lv_obj_align( label, LV_ALIGN_CENTER, 0, 0 );
#else
  // uncomment one of these demos
  //lv_demo_widgets(); // OK
  lvgl_switch_event_test();
#endif
  Serial.println("Setup done");
}


void loop()
{
  lv_timer_handler(); /* let the GUI do its work */
  delay(5);
  if (Vibration_Motor_flag_Lock == 1)
  {
    if (Vibration_Motor_flag == 1)
    {
      Vibration_Motor_flag_Lock = 0;
      set_pin_io(0, true);
      mqttClient.publish(MQTT_PUB_Vibration_Motor_S, 0, true, "ON");
    }
    else
    {
      Vibration_Motor_flag_Lock = 0;
      set_pin_io(0, false);
      mqttClient.publish(MQTT_PUB_Vibration_Motor_S, 0, true, "OFF");
    }
  }
}

static void switch_event_test_handler(lv_event_t * e)
{
  lv_event_code_t code = lv_event_get_code(e);
  if (code == LV_EVENT_VALUE_CHANGED) {
    //Serial.println("State: %s\n", lv_switch_get_state(obj) ? "On" : "Off");
    Vibration_Motor_flag = !Vibration_Motor_flag;
    Vibration_Motor_flag_Lock = 1;
  }
}

void lvgl_switch_event_test(void)
{
  lv_obj_t * label;
  /*Create a switch and apply the styles*/
  sw1 = lv_switch_create(lv_scr_act());
  lv_obj_set_width( sw1, 150);
  lv_obj_set_height( sw1, 25);
  lv_obj_add_event_cb(sw1, switch_event_test_handler, LV_EVENT_ALL, NULL);
  lv_obj_align(sw1, LV_ALIGN_CENTER, 0, 0);
  label = lv_label_create(sw1);
  lv_label_set_text(label, "Vibration_Motor");
  lv_obj_center(label);
}
